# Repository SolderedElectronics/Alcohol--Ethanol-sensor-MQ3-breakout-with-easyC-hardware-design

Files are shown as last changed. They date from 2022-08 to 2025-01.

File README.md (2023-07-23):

# Alcohol, Ethanol sensor MQ3 breakout with easyC Hardware design

## About the product

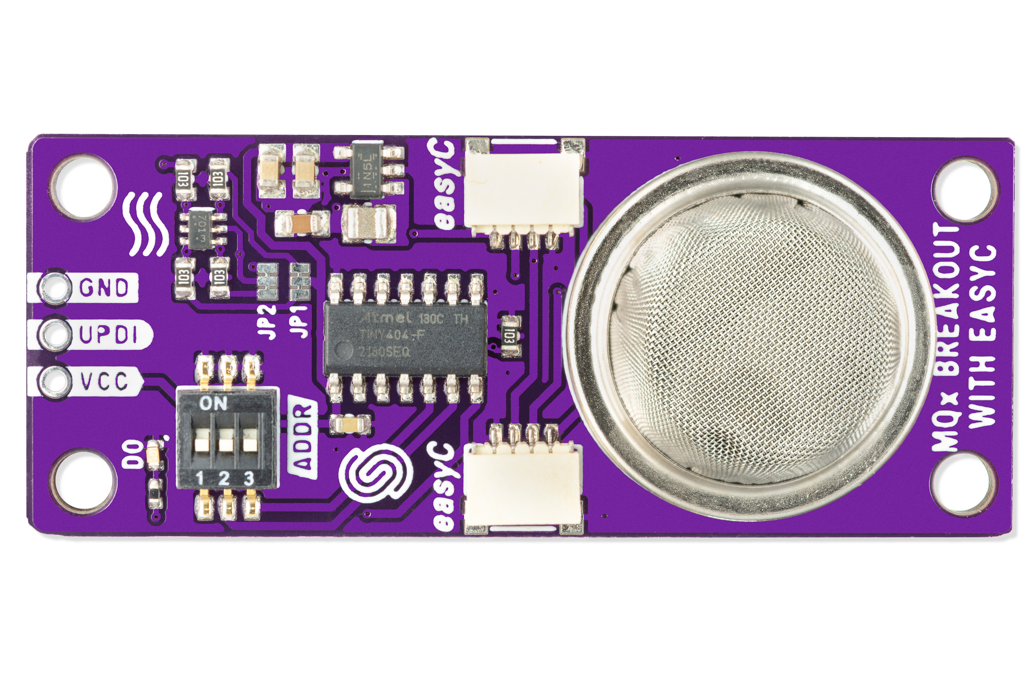
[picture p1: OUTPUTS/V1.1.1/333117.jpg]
Alcohol, Ethanol sensor MQ3 breakout with easyC
|  |
| :----------------------------------------------------------: |
|      [Buy Alcohol, Ethanol sensor MQ3 breakout with easyC](https://www.solde.red/333117)      |

MQ sensors, including the MQ3 sensor, have the capability to detect various gases. The MQ3 sensor is specifically designed to detect alcohol vapors. This means it is sensitive to alcohols such as methanol, ethanol, and isopropanol. The MQ3 sensor is commonly used for measuring alcohol concentration in the air and serves as a useful tool for alerting to the presence of alcohol in the environment.

It is important to note that MQ sensors are not specific to only one gas and can react to other gases besides the ones they are specifically designed for. Therefore, it is important to use the MQ3 sensor exclusively for alcohol detection and follow the manufacturer's instructions to achieve optimal accuracy and reliability of measurements. It requires a short time to heat up in order to work correctly.

The breakout board provides digital and analog information through the easyC system. Sensor readings are obtained through easyC.

Product usage tips:

When gas is detected, the LED will start glowing. It will remain off if it doesn't detect anything. Four mounting holes enable easy mounting to surfaces. The board comes with three male headers.

## Repository contents

All Soldered Electronics hardware designed in KiCAD, and repositories are organized in the following way:

- CAD folder - contains KiCAD files (Schematics, Board, Panel Board), sorted by version. Change log lists all changes between versions.
- OUTPUTS - contains useful files, such as Bill of Materials (BOM), PDF of schematics, 3D .step file of the board and gerber files, sorted by version. 
- OUTPUTS -> Compliance - Certificates and useful legal stuff. 

## Want to contribute?

Please feel free to submit a pull request if you have any contributions. We encourage you to submit an issue or pull request if you find a bug. 

## About Soldered

soldered-logo

At Soldered, we design and manufacture a wide selection of electronic products to help you turn your ideas into acts and bring you one step closer to your final project. Our products are intented for makers and crafted in-house by our experienced team in Osijek, Croatia. We believe that sharing is a crucial element for improvement and innovation, and we work hard to stay connected with all our makers regardless of their skill or experience level. Therefore, all our products are open-source. Finally, we always have your back. If you face any problem concerning either your shopping experience or your electronics project, our team will help you deal with it, offering efficient customer service and cost-free technical support anytime. Some of those might be useful for you:

- [Web Store](https://www.soldered.com/shop)
- [Tutorials & Projects](https://soldered.com/learn)
- [Community & Technical support](https://soldered.com/community)

## License info

All Soldered open-source hardware (OSH) is under The TAPR Open Hardware License. Read more in the LICENSE file. 

No warranty - all designs in this repository are distributed in the hope that they will be useful, but without any warranty. They are provided "AS IS", therefore without warranty of any kind, either expressed or implied. The entire quality and performance of what you do with the contents of this repository are your responsibility. In no event, Soldered Electronics will be liable for your damages, losses, including any general, special, incidental or consequential damage arising out of the use or inability to use the contents of this repository. 

## Have fun! 
And thank you from your fellow makers at Soldered Electronics.

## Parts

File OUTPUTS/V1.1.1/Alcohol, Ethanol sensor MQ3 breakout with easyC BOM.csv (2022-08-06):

Id | Designator | Package | Quantity | Designation | Supplier and ref
1 | R1,R2,R4,R5,R3 | 0603R | 5 | 10k
2 | K4 | DSHP03TS-S | 1 | DSHP03TS-S
3 | ,,,,,,,,,,,,,,,,,,,,,, | buzzardLabel | 23
4 | REF** | Logo-Back-SolderedFULL-15mm | 1 | Logo-Front-SolderedFULL-15mm
5 | U1 | MQ | 1 | MQ-X
6 | C4 | 0603C | 1 | 100n
7 | FD1 | FIDUCIAL_23 | 1 | FIDUCIAL
8 | K2 | HEADER-UPDI | 1 | HEADER-UPDI
9 | G***,G*** | Logo-Front-easyC-5mm | 2 | LOGO
10 | K3,K1 | easyC-connector | 2 | easyC-SMD
11 | JP2,JP1 | SMD_JUMPER_3_PAD_TRACE | 2 | SMD_JUMPER_3_PAD_TRACE
12 | G*** | Symbol-Front-Air-Quality | 1 | LOGO
13 | C1,C2 | 0805C | 2 | CL10A226MPCNUBE
14 | G*** | Logo-Back-OSH-3.5mm | 1 | LOGO
15 | U4 | SOIC-14 | 1 | ATTINY404-SSNR
16 | C3 | 0805C | 1 | C1608X7S1A475K080AC
17 | H2,H3,H1,H4 | HOLE_3.2mm | 4 | HOLE_3.2mm
18 | U3 | tps613222a | 1 | TPS613222A
19 | D1 | 0402LED | 1 | purple
20 | U2 | SOT-363 | 1 | NMOS-DUAL
21 | G*** | Logo-Front-Soldered-4mm | 1 | LOGO
22 | L1 | 0806L | 1 | DFE201612E-2R2M=P2
23 | R6 | 0402R | 1 | 2k2
24 | REF** | Version1.1.1. | 1 | Version1.1.1.
25 | REF** | Symbol-Front_I2C_ADDR_CUSTOM | 1 | Symbol-Front_I2C_ADDR_CUSTOM

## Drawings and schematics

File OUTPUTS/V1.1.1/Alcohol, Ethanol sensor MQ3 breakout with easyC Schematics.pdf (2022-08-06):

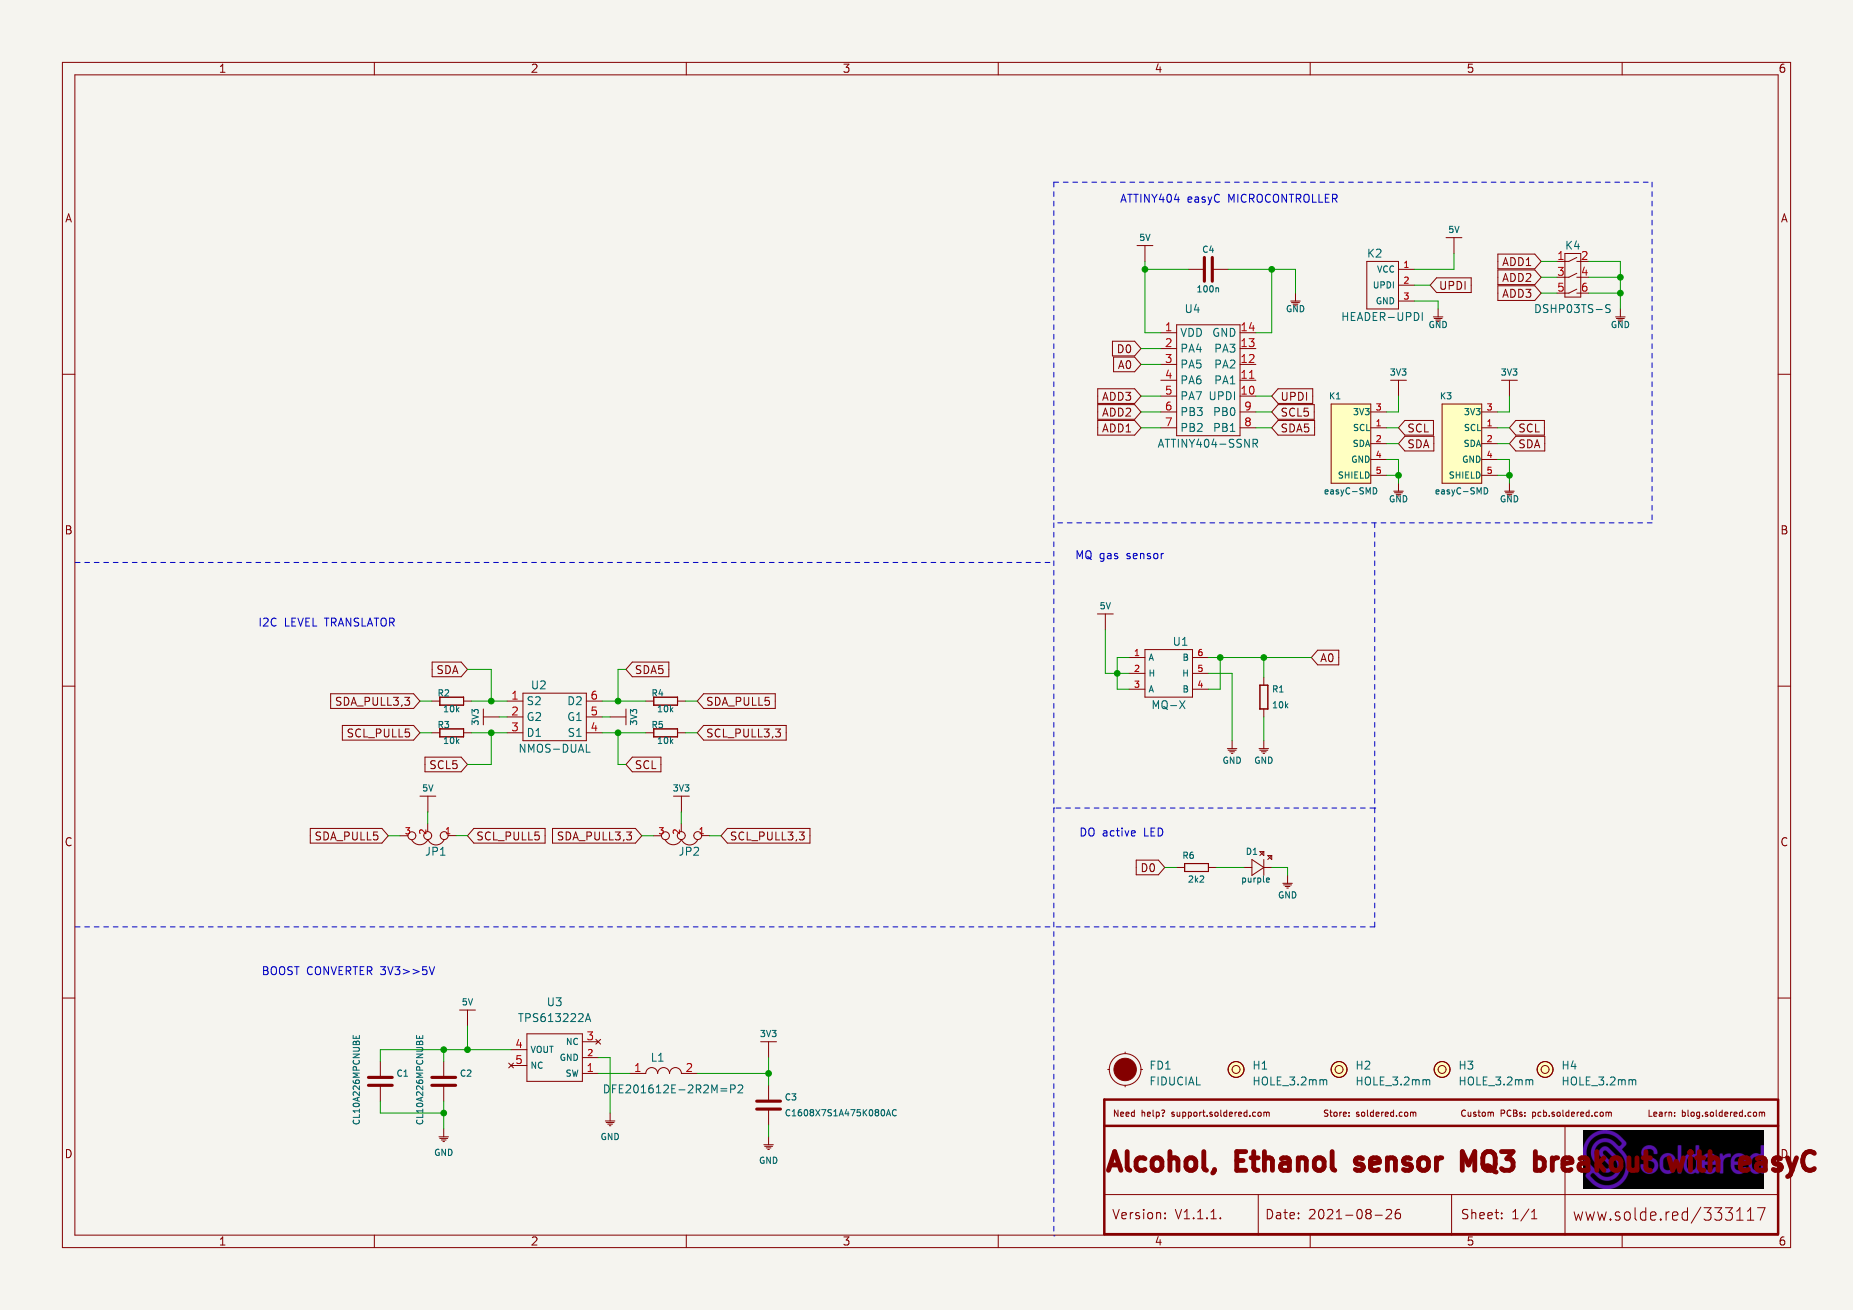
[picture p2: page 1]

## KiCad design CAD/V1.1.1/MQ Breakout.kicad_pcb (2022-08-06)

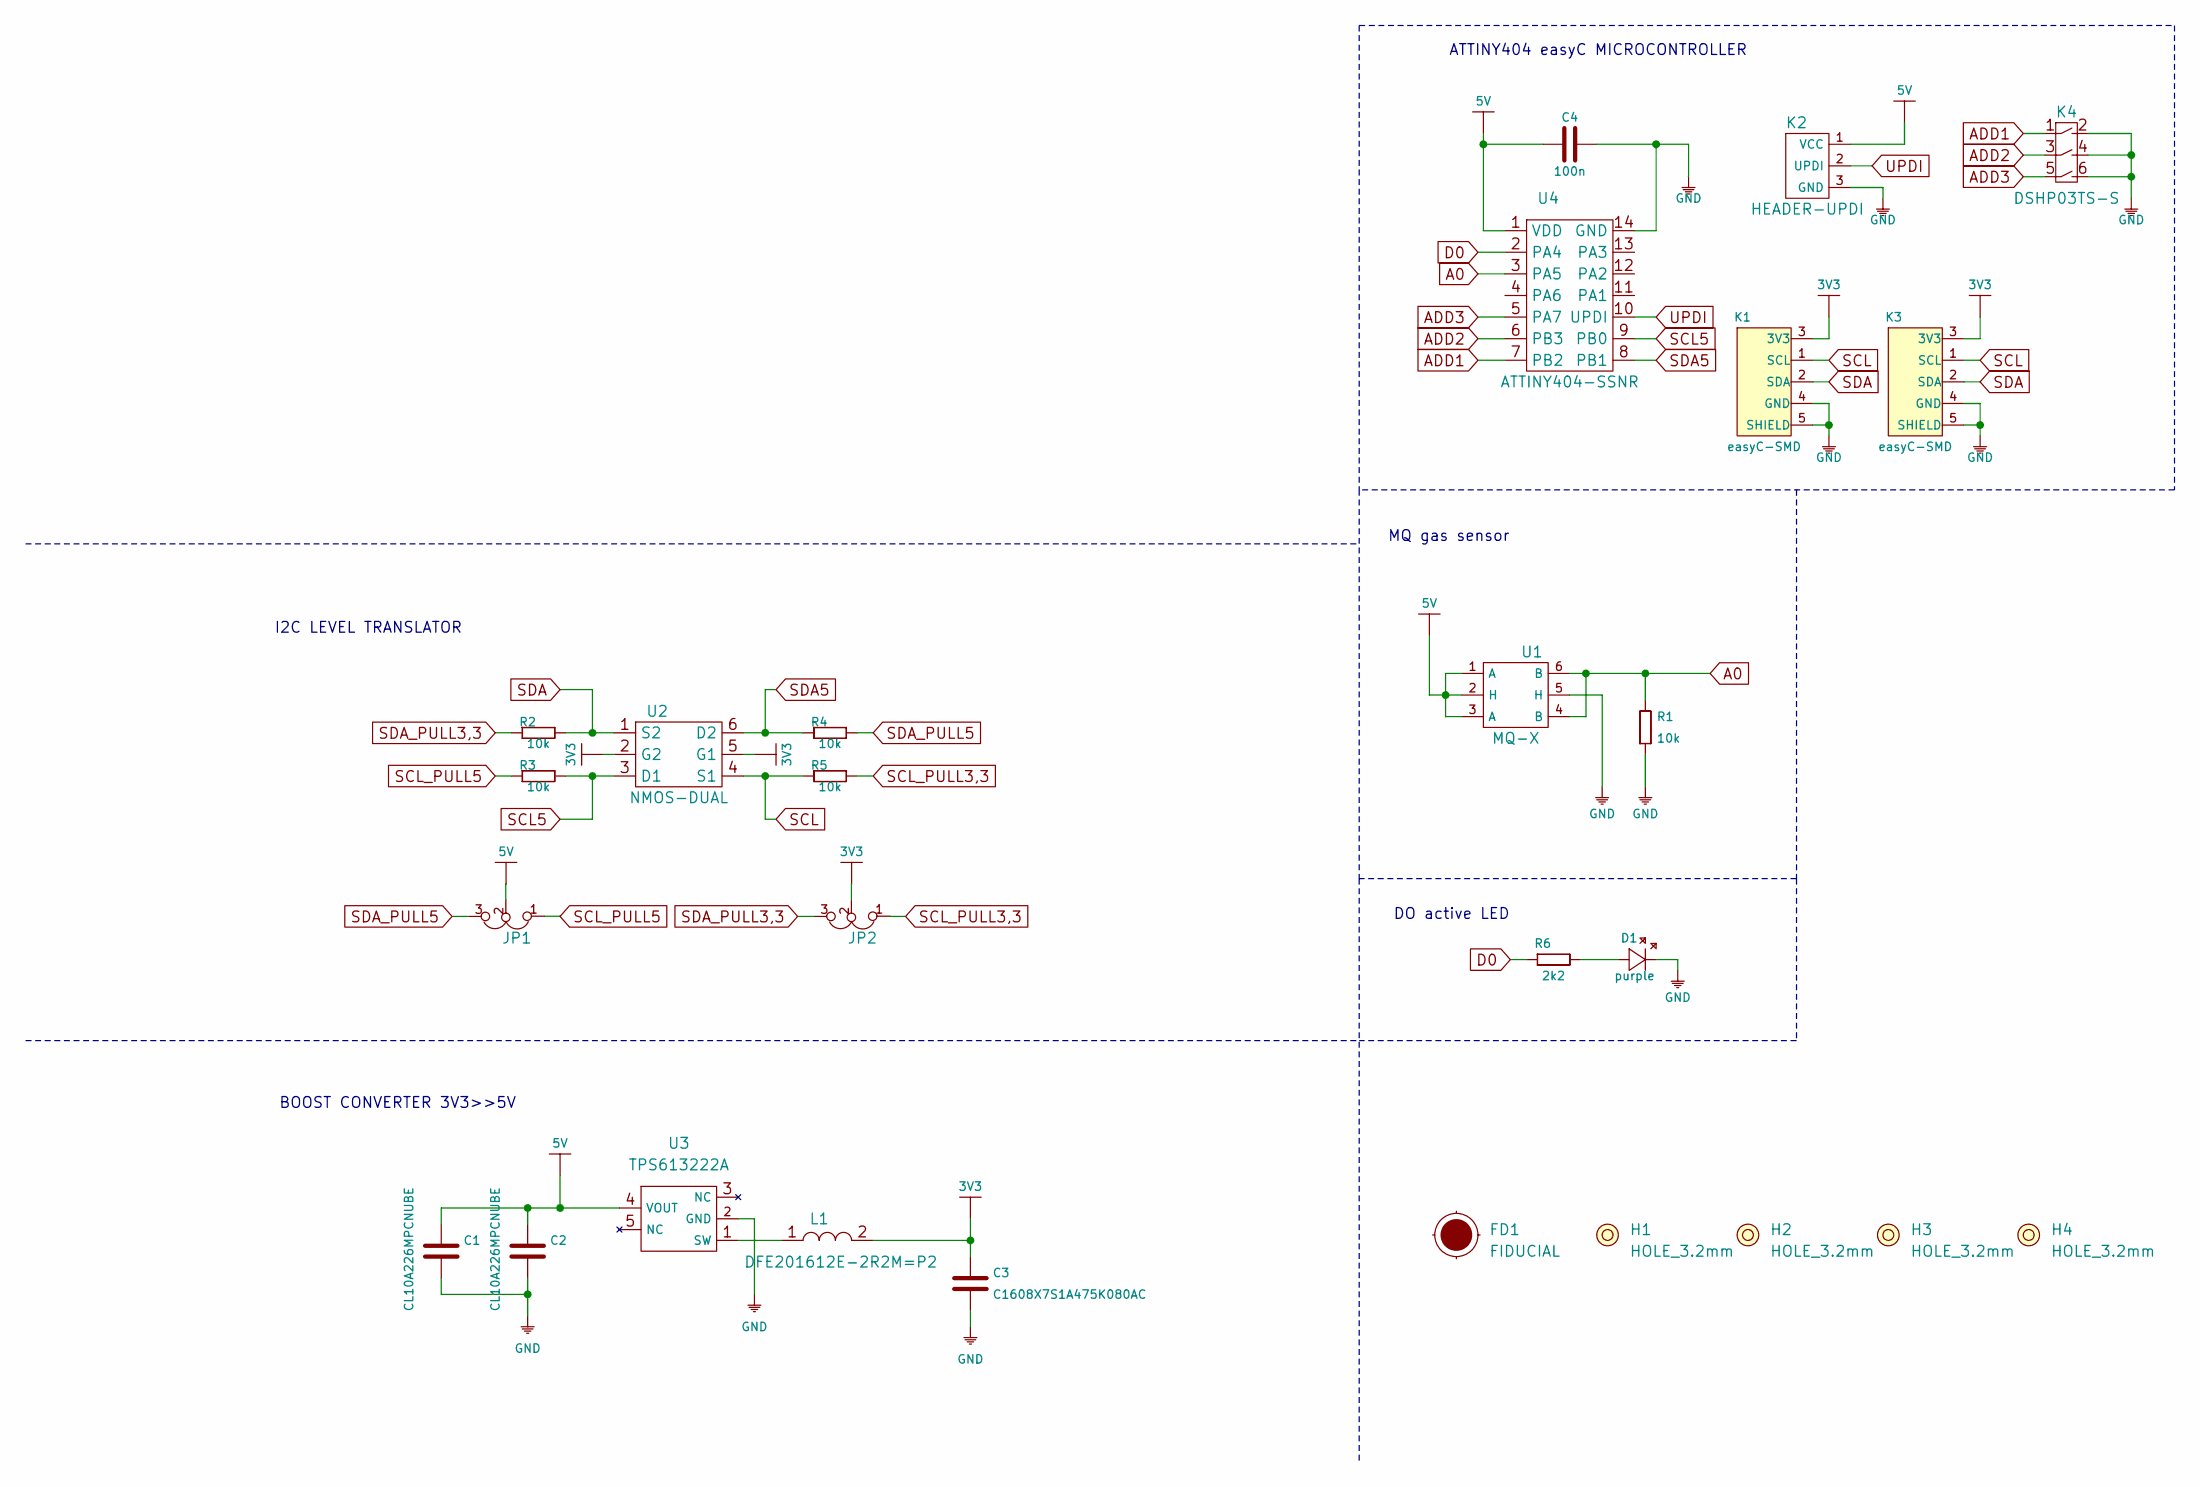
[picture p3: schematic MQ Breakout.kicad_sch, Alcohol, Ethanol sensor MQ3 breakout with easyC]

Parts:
C1, C2: CL10A226MPCNUBE; 0805C
C3: C1608X7S1A475K080AC; 0805C
C4: 100n; 0603C
D1: purple; 0402LED
FD1: FIDUCIAL; FIDUCIAL_23
H1, H2, H3, H4: HOLE_3.2mm
JP1, JP2: SMD_JUMPER_3_PAD_TRACE
K1, K3: easyC-SMD; easyC-connector
K2: HEADER-UPDI
K4: DSHP03TS-S
L1: DFE201612E-2R2M=P2; 0806L
R1, R2, R3, R4, R5: 10k; 0603R
R6: 2k2; 0402R
U1: MQ-X; MQ
U2: NMOS-DUAL; SOT-363
U3: TPS613222A; tps613222a
U4: ATTINY404-SSNR; SOIC-14

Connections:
3V3: C3.2, JP2.2, K1.3 (3V3), K3.3 (3V3), L1.2, U2.2 (G2), U2.5 (G1)
5V: C1.2, C2.2, C4.1, JP1.2, K2.1 (VCC), U1.1 (A), U1.2 (H), U1.3 (A), U3.4 (VOUT), U4.1 (VDD)
A0: R1.2, U1.4 (B), U1.6 (B), U4.3 (PA5)
ADD1: K4.1, U4.7 (PB2)
ADD2: K4.3, U4.6 (PB3)
ADD3: K4.5, U4.5 (PA7)
D0: R6.1, U4.2 (PA4)
GND: C1.1, C2.1, C3.1, C4.2, D1.2 (K), K1.4 (GND), K1.5 (SHIELD), K2.3 (GND), K3.4 (GND), K3.5 (SHIELD), K4.2, K4.4, K4.6, R1.1, U1.5 (H), U3.2 (GND), U4.14 (GND)
unnamed: D1.1 (A), R6.2
unnamed: L1.1, U3.1 (SW)
SCL: K1.1 (SCL), K3.1 (SCL), R5.1, U2.4 (S1)
SCL5: R3.2, U2.3 (D1), U4.9 (PB0)
SCL_PULL3,3: JP2.1, R5.2
SCL_PULL5: JP1.1, R3.1
SDA: K1.2 (SDA), K3.2 (SDA), R2.2, U2.1 (S2)
SDA5: R4.1, U2.6 (D2), U4.8 (PB1)
SDA_PULL3,3: JP2.3, R2.1
SDA_PULL5: JP1.3, R4.2
UPDI: K2.2 (UPDI), U4.10 (UPDI)

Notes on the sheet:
ATTINY404 easyC MICROCONTROLLER
MQ gas sensor
I2C LEVEL TRANSLATOR
DO active LED
BOOST CONVERTER 3V3>>5V

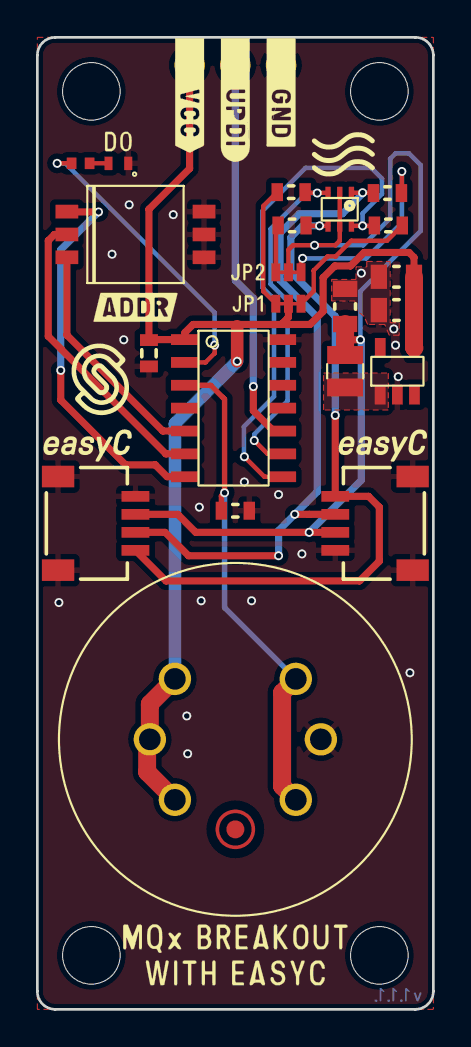
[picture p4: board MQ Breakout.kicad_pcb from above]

Board: 2 copper layers, 22.0 x 54.0 mm, 27 parts (0 on the bottom side), 19 nets.

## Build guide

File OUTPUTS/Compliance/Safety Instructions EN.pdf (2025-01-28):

PLEASE RETAIN THIS INFORMATION FOR FUTURE REFERENCE.

BEFORE USING THIS PRODUCT, READ ALL INSTRUCTION IN THIS DOCUMENT.

Product name: Alcohol, Ethanol sensor MQ3 breakout qwiic
Getting started: To get started, please visit www.soldered.com

## WARNINGS

- This product should not be covered and should be operated in well ventilated enviroment.
- The product should be placed on a stable, flat, non-conductive surface and should not be contacted by conductive items.
- Connection of other devices may affect compliance or result in damage to the unit, and invalidate the warranty.
- Where peripherals are connected that do not include the cable or connector, the cable or connector used must offer adequate insulation and operation in order that the requirements of the relevant performance and safety requirements are met.
- There is a danger of explosion if the battery is incorrectly placed.
- The product should not be used outside of its specified working range.

## INSTRUCTIONS FOR SAFE USE

To avoid malfunction or damage to your device, please observe the following:
- Do not expose it to water, moisture or place on a conductive surface when turned on. Do not handle the unit with wet hands.
- Do not expose it to heat from any source; the product is designed to be used at normal ambient room temperatures. The product is intended to be used inside.
- Take care when handling to avoid mechanical or electrical damage to any part of the unit. Avoid handling the unit while it's powered. Use ESD protection.
- Use only supplied cable (or the cable of the same or higher quality) with the unit.

## COMPLIANCE INFORMATION

The product complies with the relevant provision of the RoHS Directive for the European Union. In common with all Electrical and Electronic Equipment (EEE), the product should not be disposed household waste.

ELECTROMAGNETIC COMPABILITY AND OPERATION

- The product is in conformity with the protection requirements of EU Council Directive 2014/30/EU on the laws of the Member States relating of electromagnetic compability, and Electromagnetic Compability Regulations 2016 of the UK.
- WARNING: Please do not alter the design of this product, doing so may void your ability to use the product freely, this includes altering the frequency at which product operates.

### Regulatory Compliance and Important Safety Information

Soldered Electronics d.o.o., Vinkovačka cesta 68, 31000 Osijek, Croatia. VAT ID: HR83200237288

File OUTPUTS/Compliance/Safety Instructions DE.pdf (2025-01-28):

BITTE BEWAHREN SIE DIESE INFORMATIONEN ZUR SPÄTEREN VERWENDUNG AUF.
LESEN SIE VOR DER VERWENDUNG DIESES PRODUKTS ALLE ANWEISUNGEN IN DOKUMENT. Produktname: Alcohol, Ethanol sensor MQ3 breakout qwiic
Die ersten Schritte:Besuchen Sie www.soldered.com, um loszulegen.

## WARNUNGEN

- Dieses Produkt sollte nicht abgedeckt werden und in einer gut belüfteten Umgebung betrieben werden.
- Das Produkt sollte auf einer stabilen, flachen, nicht leitenden Oberfläche aufgestellt werden und nicht mit leitenden Gegenständen in Berührung kommen.
- Der Anschluss anderer Geräte kann die Konformität beeinträchtigen oder zu Schäden am Gerät führen und zum Erlöschen der Garantie führen.
- Wenn Peripheriegeräte angeschlossen werden, die nicht das Kabel oder den Stecker enthalten, muss das verwendete Kabel oder muss das verwendete Kabel bzw. der verwendete Steckverbinder eine angemessene Isolierung und Funktion aufweisen, damit die Anforderungen die einschlägigen Leistungs- und Sicherheitsanforderungen erfüllt werden.
- Es besteht Explosionsgefahr, wenn die Batterie falsch eingesetzt wird.
- Das Produkt sollte nicht außerhalb des angegebenen Arbeitsbereichs verwendet werden.

## HINWEISE ZUR SICHEREN ANWENDUNG

Um Fehlfunktionen oder Schäden an Ihrem Gerät zu vermeiden, beachten Sie bitte die folgenden Hinweise:
- Setzen Sie das Gerät nicht Wasser oder Feuchtigkeit aus und stellen Sie es nicht auf eine
leitende Oberfläche, wenn es eingeschaltet ist. Das Gerät nicht mit nassen Händen anfassen.
- Setzen Sie es keiner Wärmequelle aus; das Produkt ist für die Verwendung bei normalen Raumtemperaturen ausgelegt. Das Produkt ist für die Verwendung in Innenräumen vorgesehen.
- Seien Sie bei der Handhabung vorsichtig, um mechanische oder elektrische Schäden an Teilen des Geräts zu vermeiden. Fassen Sie das Gerät nicht an, wenn es unter Spannung steht. Verwenden Sie einen ESD-Schutz.
- Verwenden Sie nur das mitgelieferte Kabel (oder ein gleich- oder höherwertiges Kabel)
mit dem Gerät.

## COMPLIANCE-INFORMATIONEN

Das Produkt entspricht den entsprechenden Bestimmungen der RoHS-Richtlinie für die Europäische Union. Wie alle elektrischen und elektronischen Geräte (EEE), sollte das Produkt nicht über den Hausmüll entsorgt werden.
ELEKTROMAGNETISCHE VERTRÄGLICHKEIT UND BETRIEB
- Das Produkt entspricht den Schutzanforderungen der Richtlinie des EU-Rates 2014/30/EU über die Rechtsvorschriften der Mitgliedstaaten zur elektromagnetischen Verträglichkeit und den Elektromagnetische Verträglichkeitsverordnung 2016 des Vereinigten Königreichs.
- WARNUNG: Bitte verändern Sie nicht das Design dieses Produkts, da dies dazu führen kann, dass Sie das Produkt nicht mehr uneingeschränkt nutzen können.
Dies gilt auch für die Änderung der Frequenz, mit der das Produkt arbeitet.

## Einhaltung gesetzlicher Vorschriften und wichtige

Soldered Electronics d.o.o., Vinkovačka cesta 68, 31000 Osijek, Croatia. VAT ID: HR83200237288

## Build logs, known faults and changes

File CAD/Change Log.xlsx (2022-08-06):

CHANGE LOG
 | Latest version |  |  | v1.0.0.
 |  | Product name: |  | Alcohol, Ethanol sensor MQ3 breakout with easyC
 |  | Release date: |  | 20.7.2021.
 |  | Release author: |  | David Zovko
Version: | v1.0.0. | Author: | David Zovko | Date: | 20.7.2021.
List of Changes
 | Initial document
Version: | v1.1.1 | Author: | Ivan Fadiga | Date: | 26.8.2021.
List of Changes
 | Connect sensor output to Attiny404 pin 3 (PA5)
 | ADD I2CADDR label
 | ADD tags for jumper
 | Move resistor R1
 | Update MQ sensor outline
Version: |  | Author: |  | Date:
List of Changes
